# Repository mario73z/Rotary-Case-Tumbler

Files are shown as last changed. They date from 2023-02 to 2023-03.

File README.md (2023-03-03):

# Rotary-Case-Tumbler
Tumbler do mokrego mycia łusek

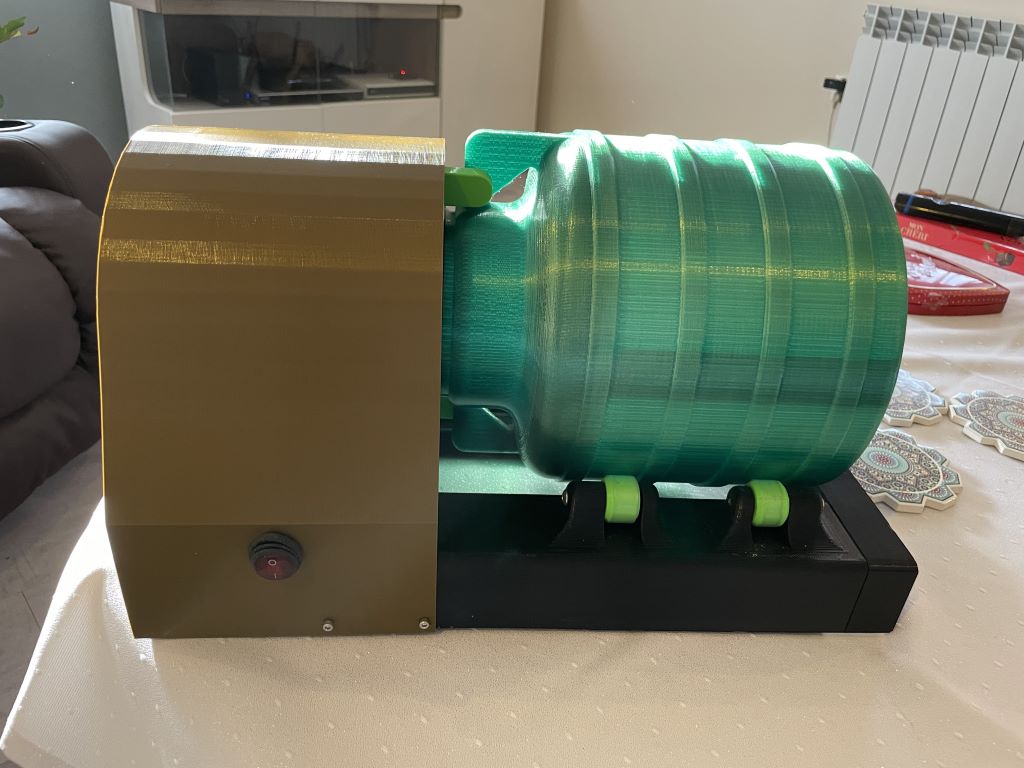
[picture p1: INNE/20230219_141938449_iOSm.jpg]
Image of Tumbler by Mario


Hej

Jeden z istotnych i nieco żmudnych etapów elaboracji amunicji to czyszczenie łusek lub nanoszenia powłok na pociski. Oczywiście jest mnóstwo tego typu urządzeń na rynku za mniejsze lub większe pieniądze. Ja jednak lubię projektować, i nie mniej ważne jak cel jest dla mnie też sama droga do niego, więc pochyliłem się nad tematem. Jako że to bardzo proste urządzenie, może go zbudować praktycznie każdy kto ma chociażby podstawy w elektronice i montażu urządzeń. 

Całość zasilamy napięciem 12v, zasilacz musiał by wytrzymać obciążenia 2A

Sam napęd można zrobić na kilka sposobów, W projekcie użyłem „arduino nano” i sterownik  drv8825. Prosty szablon na arduino daje pełną kontrole nad kierunkiem, prędkością i czasem działania procesu czyszczenia. Użyłem ustawienia dla sterownika 1/16 kroku. 

Jako element bębnowy można wykorzystać beczkę 5L z linku podanego w arkuszu. Koszt niewielki jednak konieczne jest wklejenie kilku (4) „występów” w środku beczki aby wsyp się przesypywał a nie jedynie przetaczał.
Drugą opcją jet druk takiej beczki. Projekt obejmuje również i takie rozwiązanie. Do uszczelnienia wieczka można użyć recepturek odpowiedniej średnicy. 

Większość elementów to druk 3D. Drukować proponuję z minimum 30% wypełnieniem. Sugeruję PET-G, jednak przy tych rozmiarach i wypełnieniu druk z PLA wydaje się być również wystarczający. 
Elementy obrotowe są łożyskowane na łożyskach 625 po dwa w każdą rolkę i dwa w przeniesienie napędu z silnika. Dla sztywności kół zębatego i napędowego użyłem aluminiowych kół GT2 20T, Należy po zdjęciu z nich kołnierza wcisnąć w druk i przykręcić M3x15. Na stalowej ośce 5x50 zapewni wystarczającą sztywność.

Do zaprojektowania używałem darmowego programu DesignSpark Mechanical. Udostępniam oprócz wszystkich plików stl również bazowy plik z w.w  programu ( CAD ) więc każdy kto będzie miał ochotę i pomysł na zmiany może sobie projekt dowolnie zmienić.

I tym sposobem można sobie samemu zbudować myjkę za niewielkie pieniądze, satysfakcja z takiej budowy to wielki bonus, przynajmniej dla mnie. Ufam że przez to udostępnienie i dla Was. 

Powodzenia :)

https://youtu.be/VPBSpM66at4 

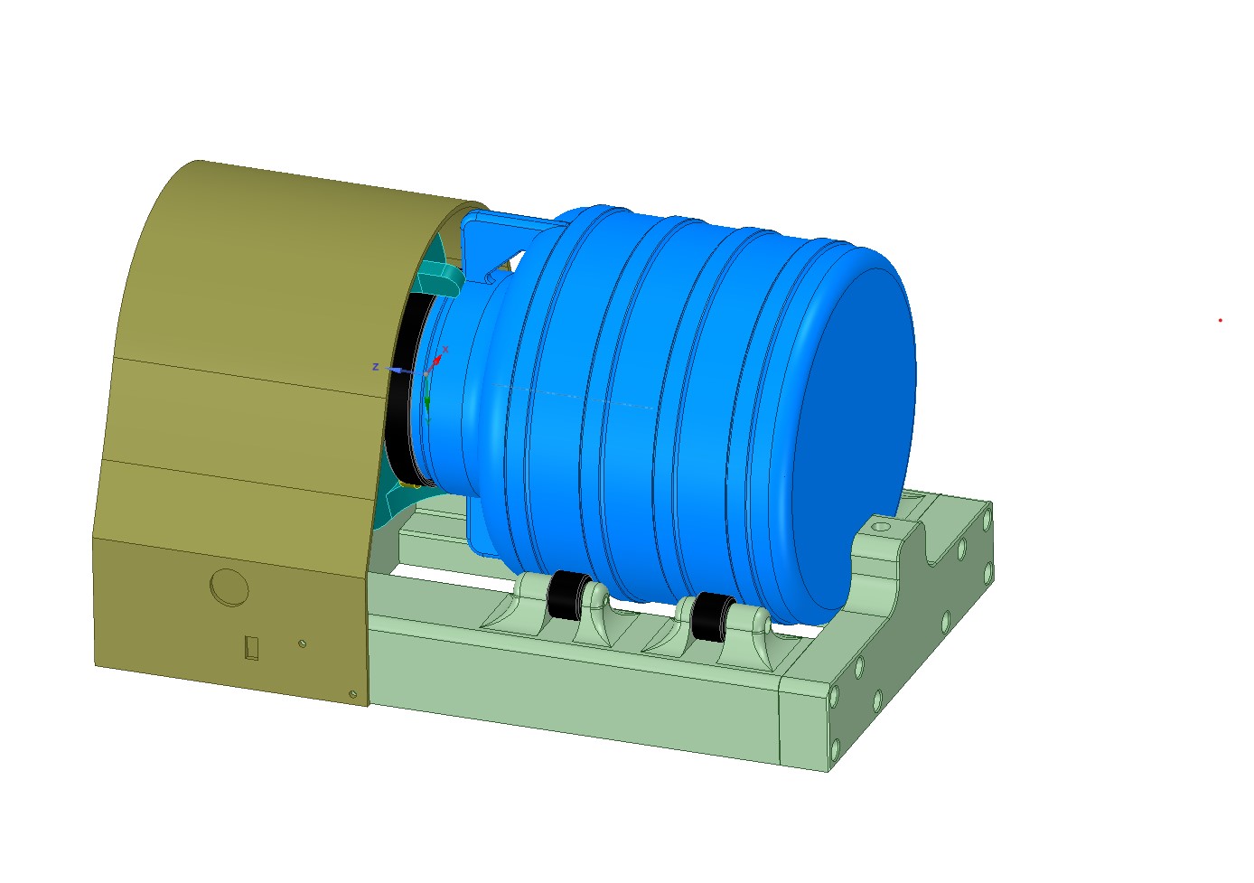
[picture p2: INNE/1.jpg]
Image of Tumbler by Mario cad


# Nowe wersja bębna
03.03.2023

Na Waszą prośbę w katalogu v_2-0-2  dodałem poprawioną wersję bębna. Jest to wersja z zakrętką i pomniejszonymi wypustami wewnętrznymi. Zoptymalizowany został też projekt pod względem druku 3D, poprawiłem też niewielkie niedociągnięcia w projekcie cad.

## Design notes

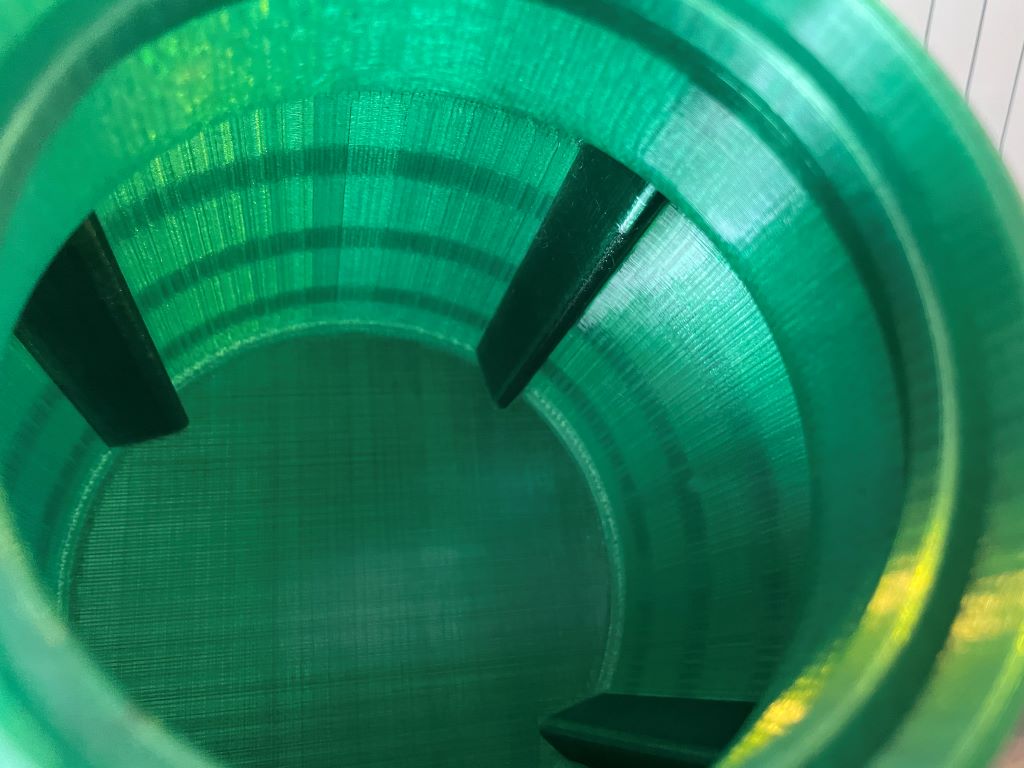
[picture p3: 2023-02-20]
INNE/20230219_142151895_iOSm.jpg

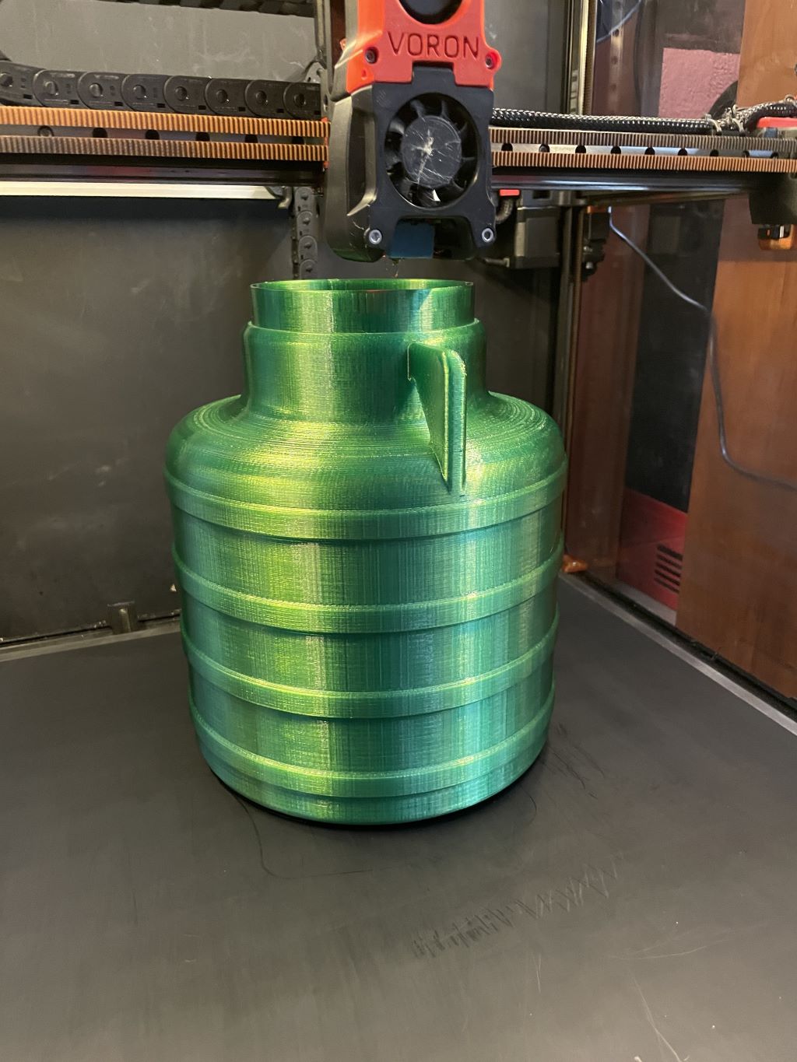
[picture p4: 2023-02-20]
INNE/20230219_065700779_iOSm.jpg

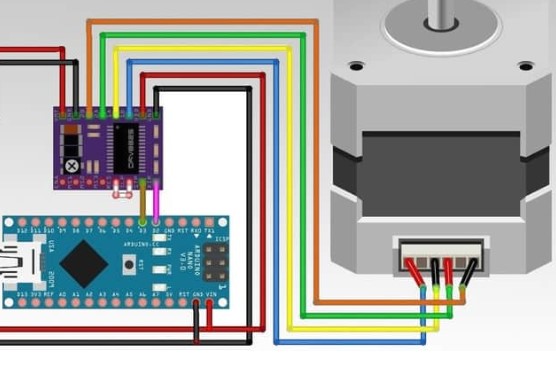
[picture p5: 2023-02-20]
INNE/schemat.jpg

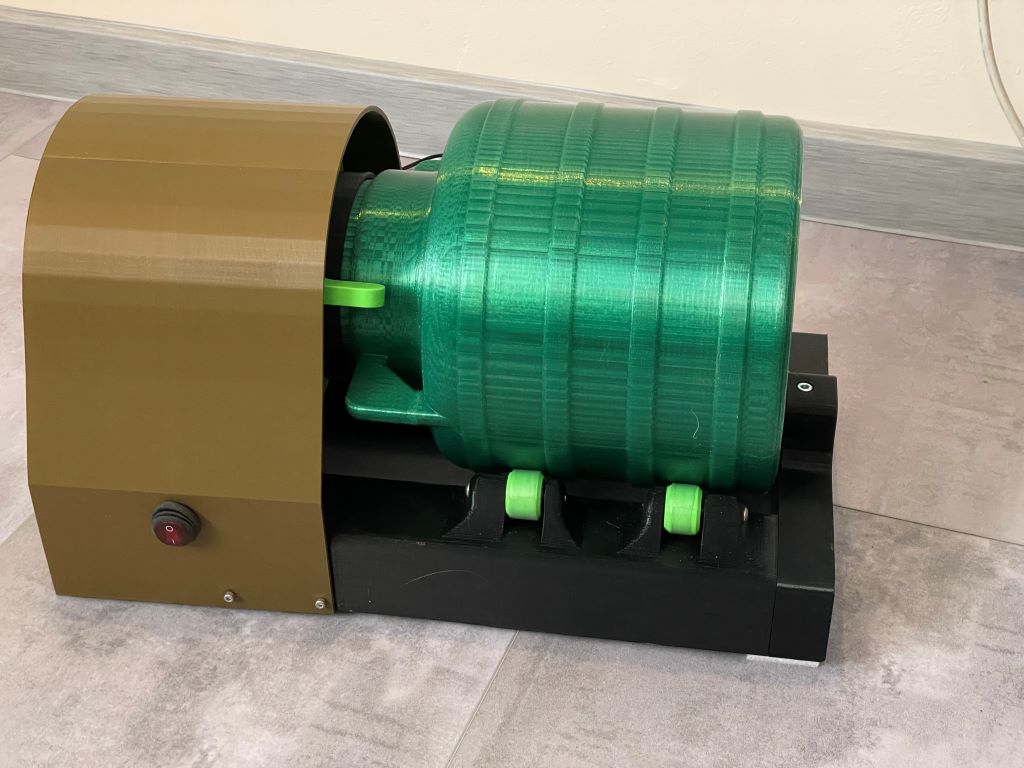
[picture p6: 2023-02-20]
INNE/20230219_142329965_iOSm.jpg

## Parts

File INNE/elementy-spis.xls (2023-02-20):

nazwa | przykładowy link do zakupu | sumy w zł.
Silnik nema 17 1.5A | https://allegro.pl/oferta/silnik-krokowy-nema17-42mm-1-5a-0-45nm-drukarka-3d-7783022462 | 20.00 zł
Steper driver – płytka | https://allegro.pl/oferta/plytka-rozszerzen-sterownika-do-drukarki-3d-42-13226524901 | 14.00 zł
sterownik silnika | https://allegro.pl/oferta/drv8825-sterownik-silnika-krokowego-stepstick-6948986224 | 14.00 zł
arduino nano | https://allegro.pl/oferta/arduino-nano-v3-0-atmega328p-ch340-zlutowany-mini-12124054156 | 30.00 zł
M5x30 21 sztuk |  | 8.00 zł
M3x15 19szt |  | 5.00 zł
M3x25 4szt. |  | 2.00 zł
Pasek GT2 | https://allegro.pl/oferta/pasek-zebaty-petla-188-mm-gt2-szer-6-mm-8130335051 | 6.00 zł
włącznik | https://allegro.pl/oferta/przelacznik-kolyskowy-12v-wlacznik-podswietlany-10200388661 | 6.00 zł
Gniazdo zasilacza | https://allegro.pl/oferta/gniazdo-zasilacza-dc-2-1-5-5-do-obudowy-10798342729 | 5.00 zł
Filament 2kg | https://allegro.pl/oferta/filament-colorfil-abs-gray-1-75mm-1kg-12135352869 | 90.00 zł
koła zębate GT2 20T 3szt | https://allegro.pl/oferta/kolo-zebate-do-paska-klinowego-rainbowsemi-gt2-20t-11813889296 | 16.00 zł
Łożysko 625 12szt. | https://allegro.pl/oferta/lozysko-kulkowe-625-2rs-5x16x5mm-komplet-10szt-9802693152 | 13.00 zł
Bęben | https://allegro.pl/oferta/beczka-plastikowa-na-wode-wieczko-atest-zywnosc-5l-12370419965 | 15.00 zł
 |  | 244.00 zł

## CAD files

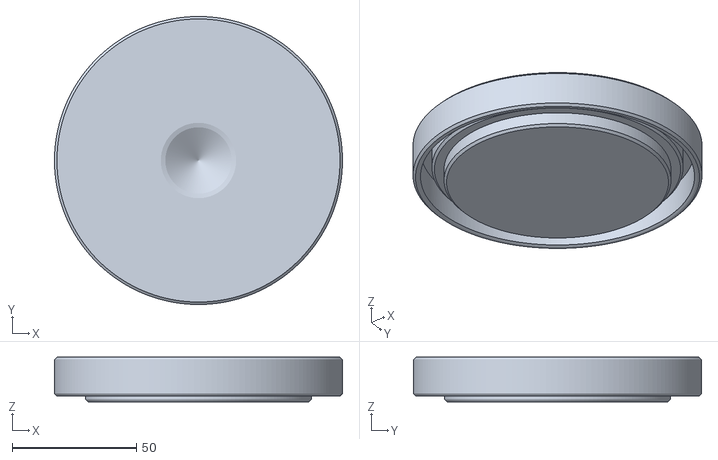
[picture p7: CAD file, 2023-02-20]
STL/beben/korek-bebna.stl
116.0 x 116.0 x 18.0

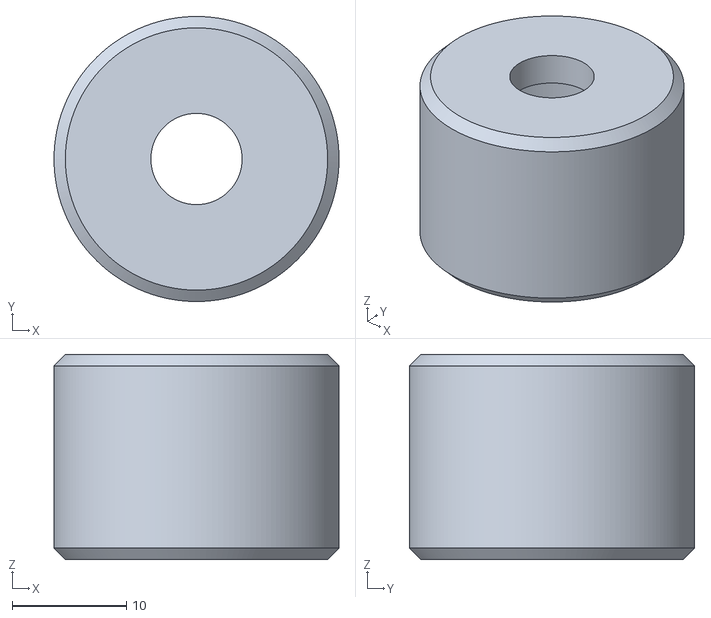
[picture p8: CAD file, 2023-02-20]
STL/rolka-5szt.stl
25.0 x 25.0 x 18.0

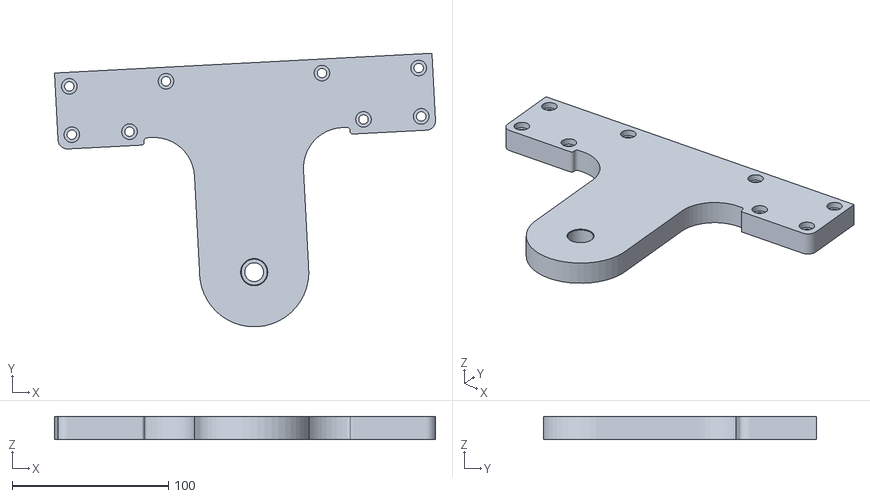
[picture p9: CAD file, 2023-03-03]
v_2-0-2/stl/podpora-przednia-rama.stl
243.9 x 175.1 x 15.0

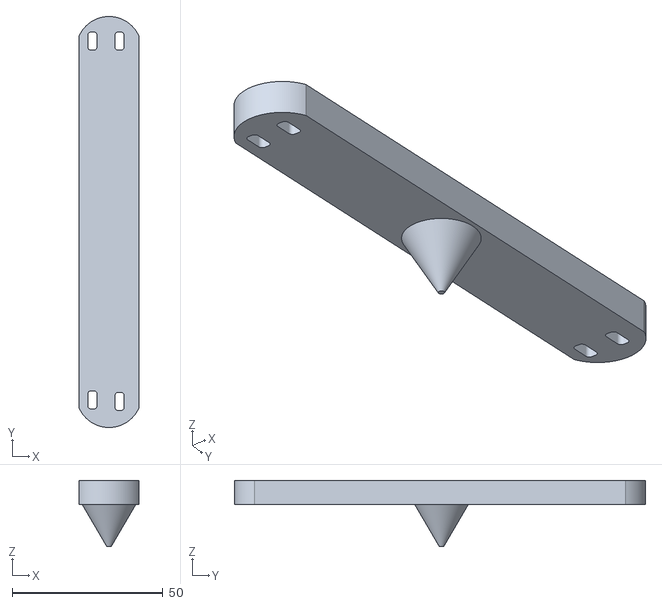
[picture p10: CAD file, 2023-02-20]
STL/beben/blokada-korka-bebna.stl
20.0 x 136.4 x 22.0

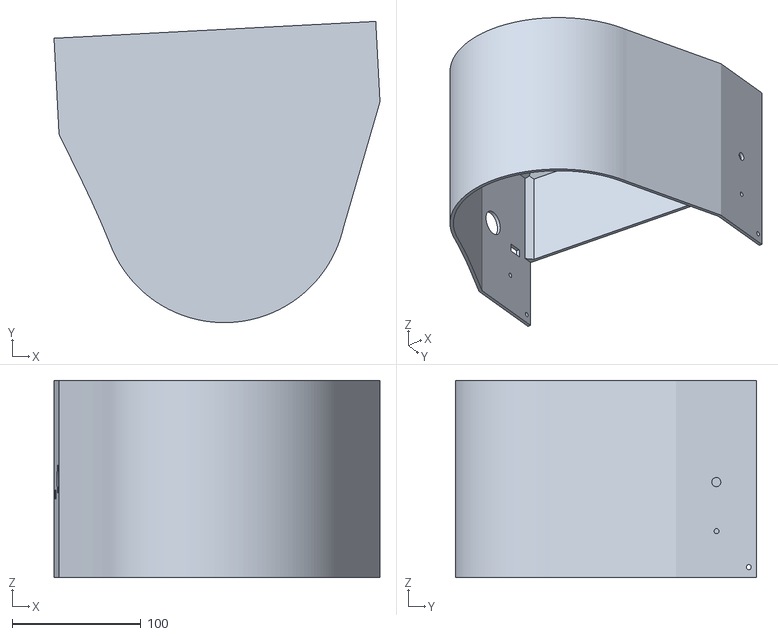
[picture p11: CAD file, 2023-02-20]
STL/oslona-maskownica-napedu.stl
252.9 x 233.7 x 153.0

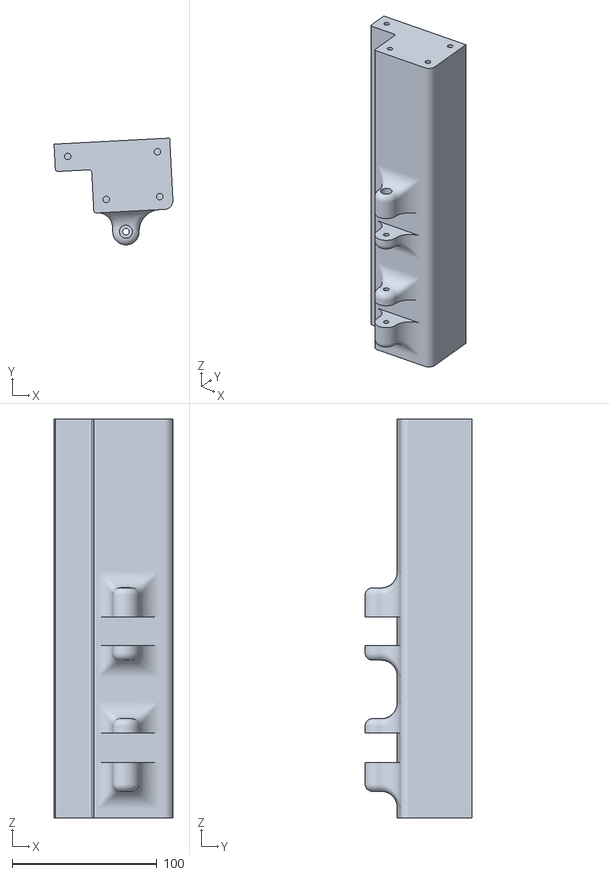
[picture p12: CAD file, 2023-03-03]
v_2-0-2/stl/rama-l-d.stl
82.1 x 73.8 x 275.5

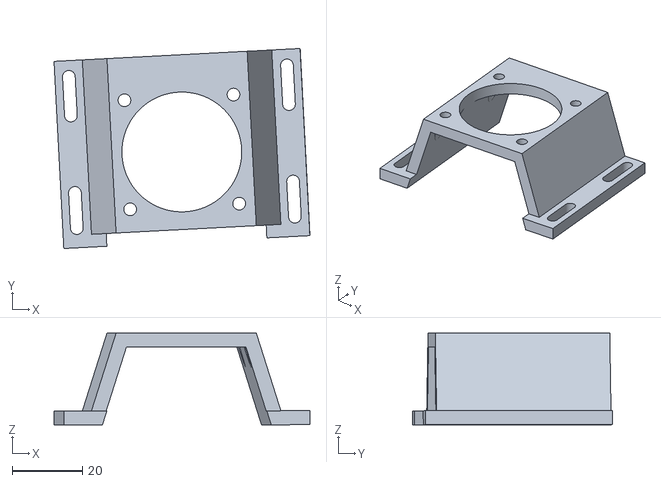
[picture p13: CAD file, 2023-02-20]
STL/mocowanie-silnika.stl
72.7 x 56.8 x 26.1

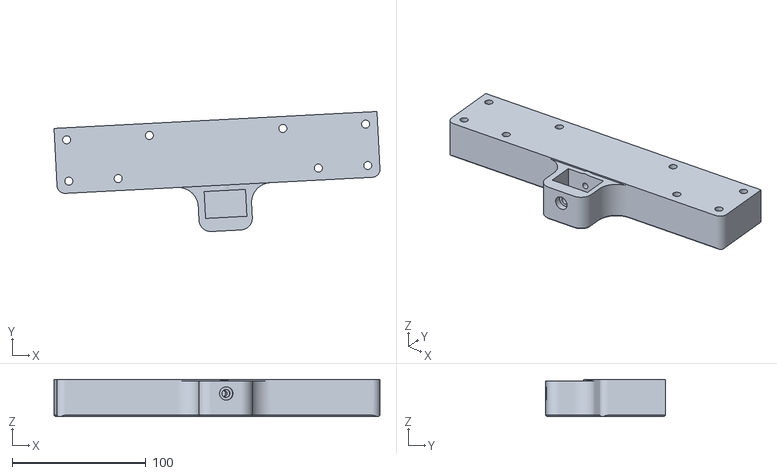
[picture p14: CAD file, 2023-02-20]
STL/rama-t-p.stl
243.9 x 89.8 x 27.8

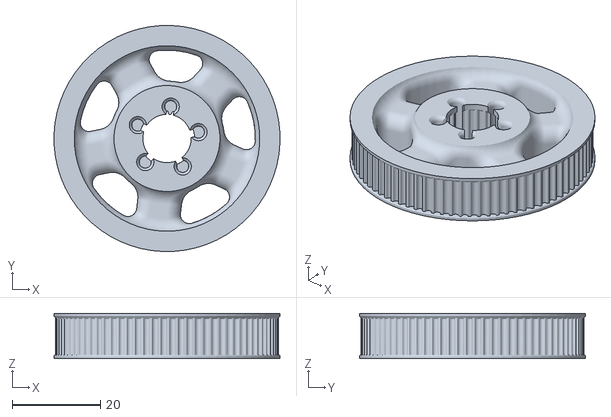
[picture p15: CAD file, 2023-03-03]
v_2-0-2/stl/kolo-napedowe-male.stl
51.2 x 51.2 x 10.2

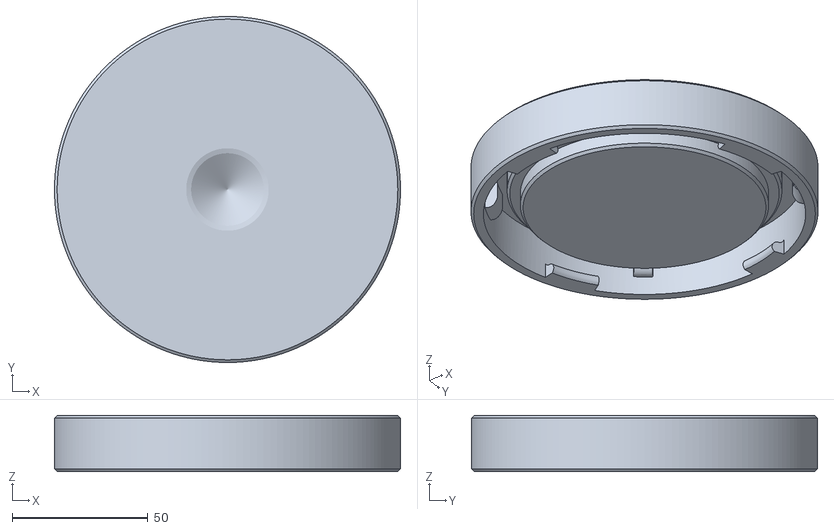
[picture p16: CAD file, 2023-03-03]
v_2-0-2/stl/korek-bebna-2-0-2.stl
127.3 x 127.3 x 20.7

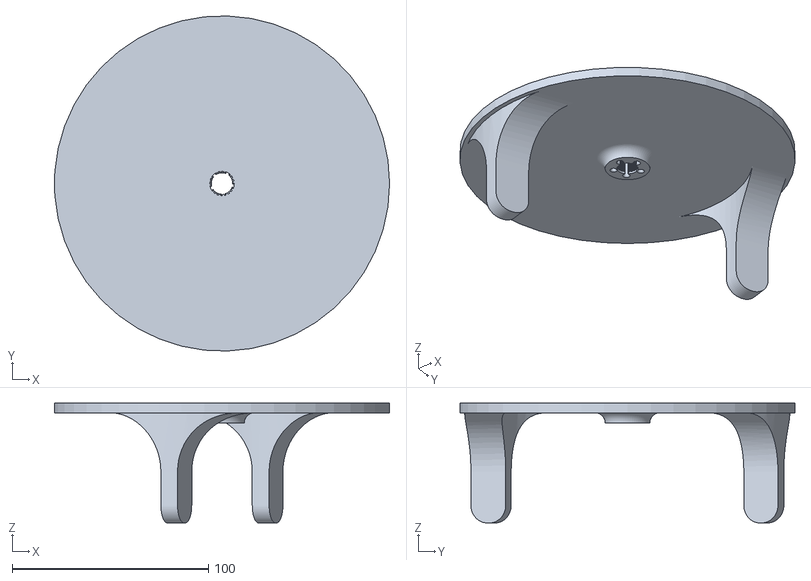
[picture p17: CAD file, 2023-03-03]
v_2-0-2/stl/kolo-napedowe-duze.stl
171.0 x 170.8 x 61.2

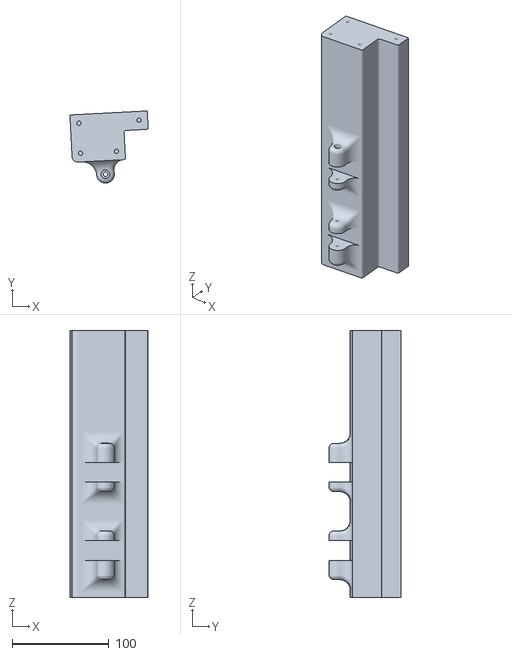
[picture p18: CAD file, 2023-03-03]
v_2-0-2/stl/rama-p-d.stl
80.8 x 74.5 x 275.5

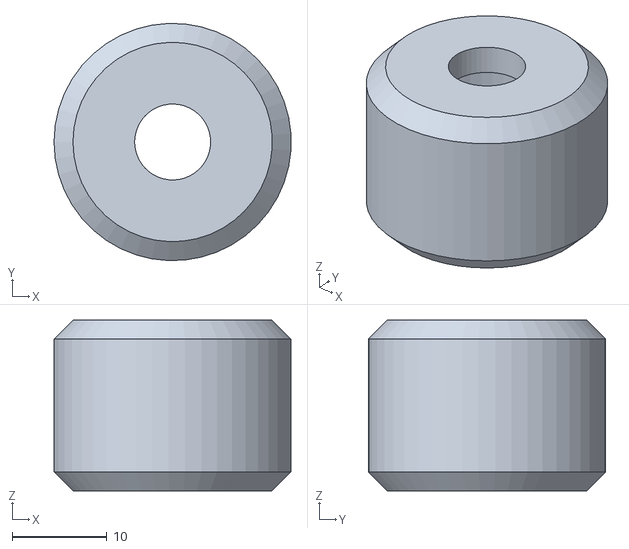
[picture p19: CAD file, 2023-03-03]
v_2-0-2/stl/rolka-x5.stl
25.0 x 25.0 x 18.0

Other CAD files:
v_2-0-2/stl/mocowanie-silnika.stl
v_2-0-2/stl/blokada-korka-bebna.stl
v_2-0-2/stl/oslona-maskownica-bok.stl
v_2-0-2/stl/podpora-tyl-rama.stl
